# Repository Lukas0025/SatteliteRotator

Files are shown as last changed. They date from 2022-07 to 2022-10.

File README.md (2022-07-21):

# Sattelite (antenna) Rotator (OpenSource and Open-source hardware) (HamLIB, Gpredict, satNOGS) (Linear motor EL)

Simple arduino antenna rotator with two axis (AZ and EL). For AZ is used step motor and for EL is used linear motor. 
For controll is created PCB with Arduino nano, step motor driver and four relays. Controller uses easycomm and rotator can work with HAM Lib, Gpredict, SatNOGS, ...

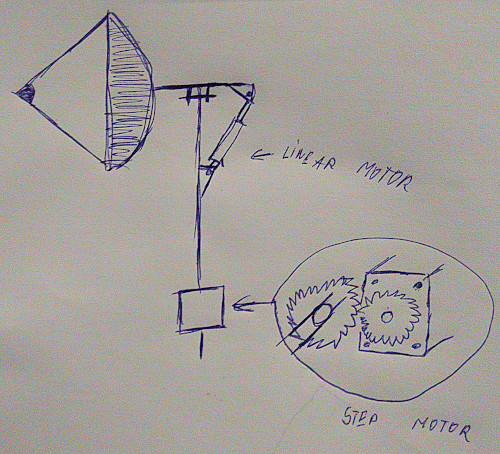
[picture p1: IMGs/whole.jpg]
Whole


## Rotator setup

### Azimuth

For azimuth rotator can by used simply one gear on rope and step motor like here https://www.thingiverse.com/thing:4246844 or can by used some old HAM rotator and replace rotary pin with step motor.

* Step motor and rope

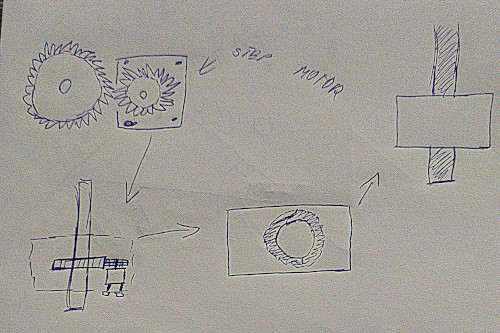
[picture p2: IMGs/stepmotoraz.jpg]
StepMotor


* Step motor and old rotator

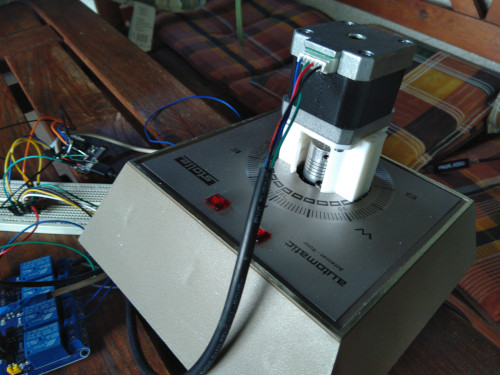
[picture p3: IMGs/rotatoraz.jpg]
OldRotator


### Elevation

For elevation is used linear motor more info is here https://www.qsl.net/sv1bsx/actuator/actuator.html

Elevation
Elevation_open

## Controller board

Board using Arduino Nano as microcontoler, A4988 for drive stepmotor, external 4 relay board for drive linear motor and same extesion ports. Board is designed in Kicad.

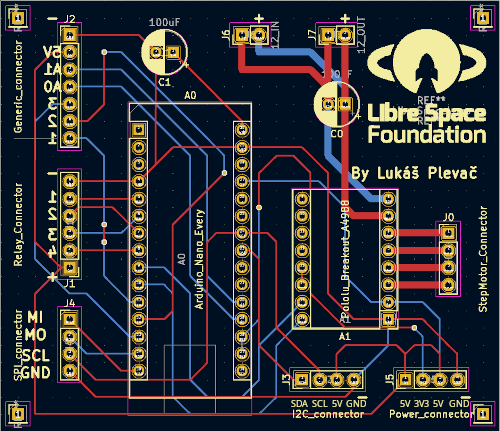
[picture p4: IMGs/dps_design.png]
Board


### Parts:

* Arduino Nano (https://www.ebay.com/itm/384943705316)
* A4988 Driver (https://www.ebay.com/itm/221921771119)
* 4 relay borad (4 channels) (https://www.ebay.com/itm/295078400027)
* 2x 100uF capacitator
* 2x 2 Pin 2.54mm Pitch PCB Screw Terminal Block (https://www.ebay.com/itm/264467271488)
* 2x 15pin 2.54mm Long Pin Female Header (https://www.ebay.com/itm/223478558792)
* 2x 8pin 2.54mm Long Pin Female Header (https://www.ebay.com/itm/223478558792)
* 1x 4pin 2.54mm Long Pin Male Header
* prited PCB 

### Extension ports

* Generic ports - 3 digitals and 2 analog ports
* SPI port
* I2C port
* power port - 5V, 3V3 and GND
* 2 relays

### Ports mapping

|  Boards | Arduino Nano |
|---|---|
| Relay 1 | D2 |
| Relay 2 | D4 |
| Relay 3 | D3 |
| Relay 4 | D5 |
| Step Motor Step  | D6 |
| Step Motor Dir | D7 |
| Generic 1 | D8 |
| Generic 2 | D9 |
| Generic 3 | D10 |
| A0 | A0 |
| A1 | A1 |
| MI | MISO |
| MO | MOSI |
| SCK | SCK |
| SDA (I2C) | SDA/A4 |
| SCL (I2C) | SCL/A5 |

## Connect with PC (HamLib, Gpredict, ...)

After code uploaded to arduino you need run rotctld for parse easycomm comunication.

```sh
sudo rotctld -m 202 -r /dev/ttyACM0 -s 9600 -T 127.0.0.1 -t 4533 -C timeout=5000 -C retry=0 -vvvvvvvv > pause
```

Connect to Gpredict using add rotator to Gpredict in Edit > Settings > Interface > Rotators > add new

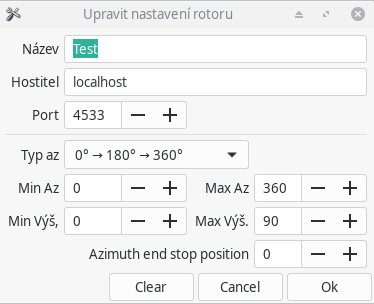
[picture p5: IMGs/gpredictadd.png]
Add New


then you can use rotator in Antenna controller

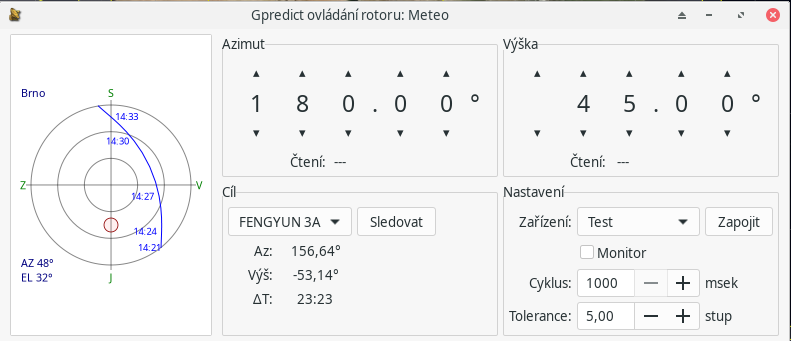
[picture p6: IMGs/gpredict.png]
Gpredict


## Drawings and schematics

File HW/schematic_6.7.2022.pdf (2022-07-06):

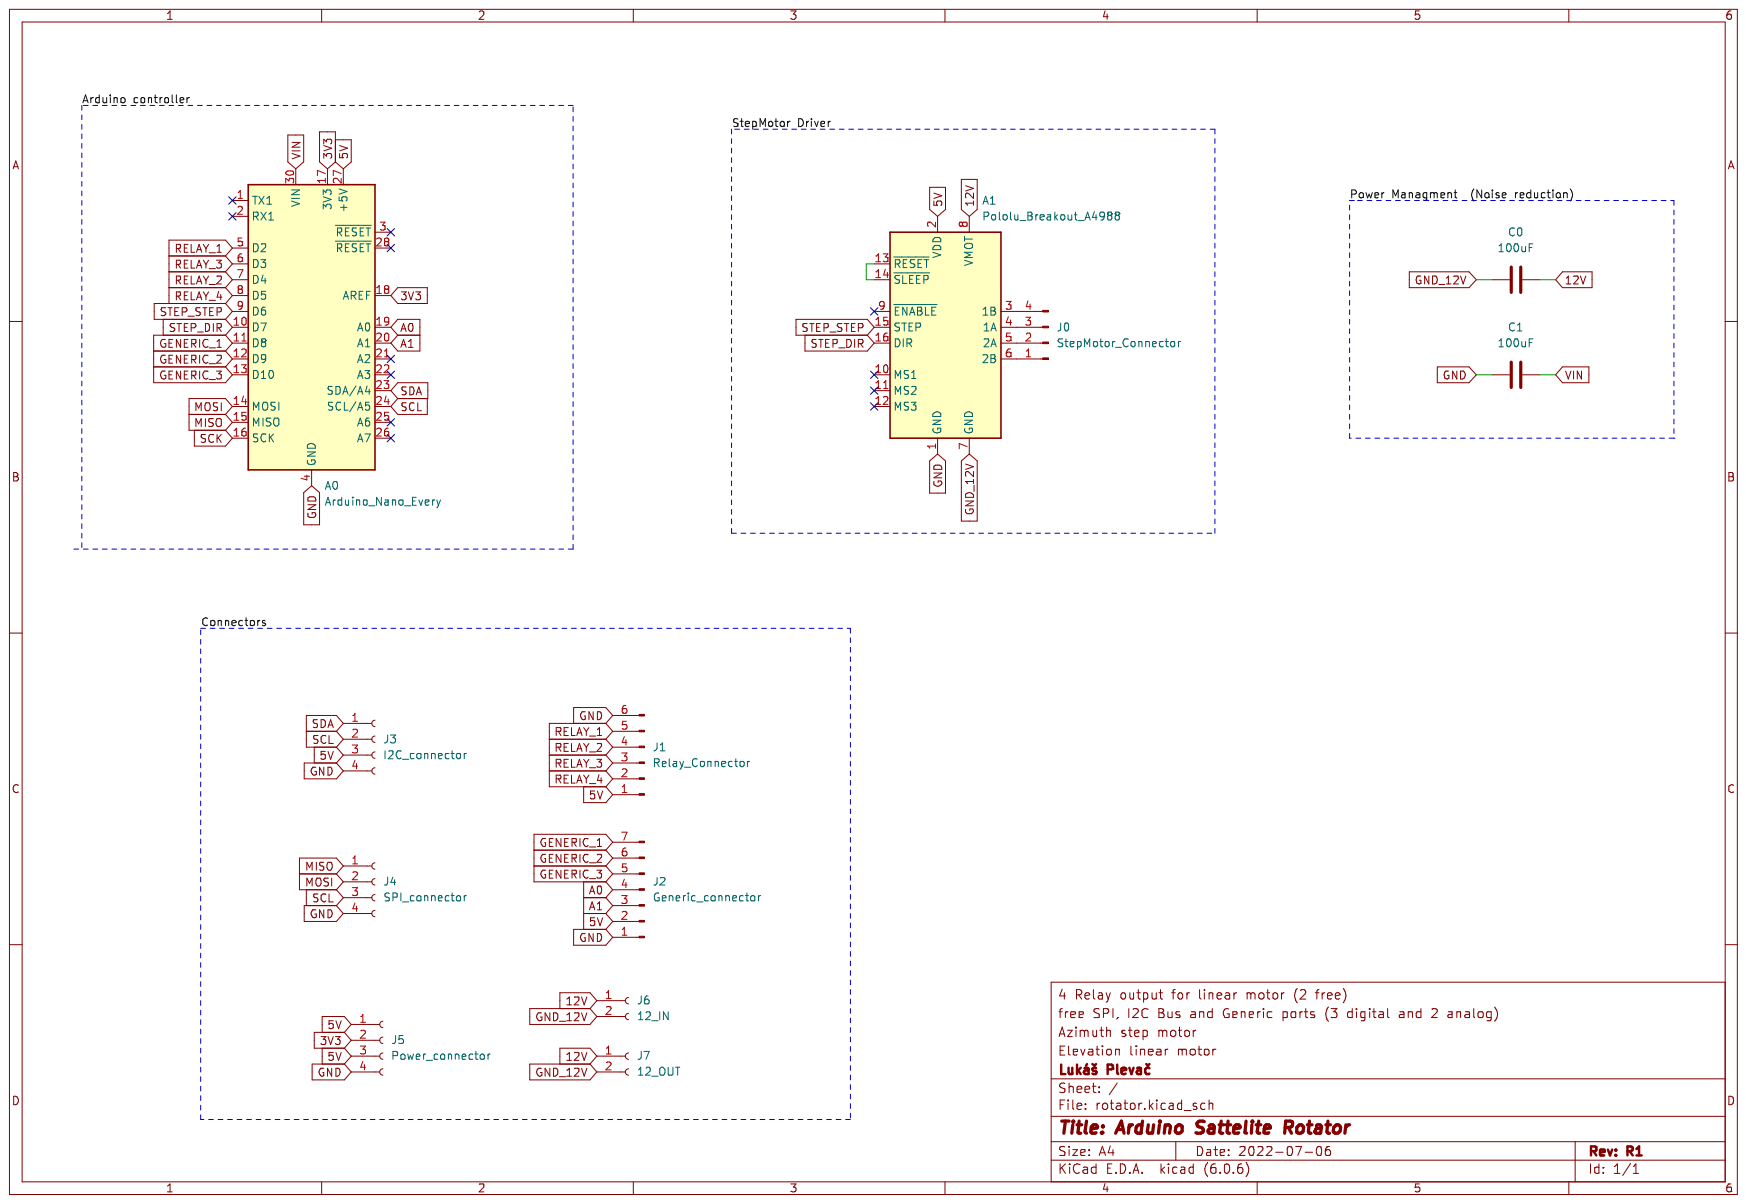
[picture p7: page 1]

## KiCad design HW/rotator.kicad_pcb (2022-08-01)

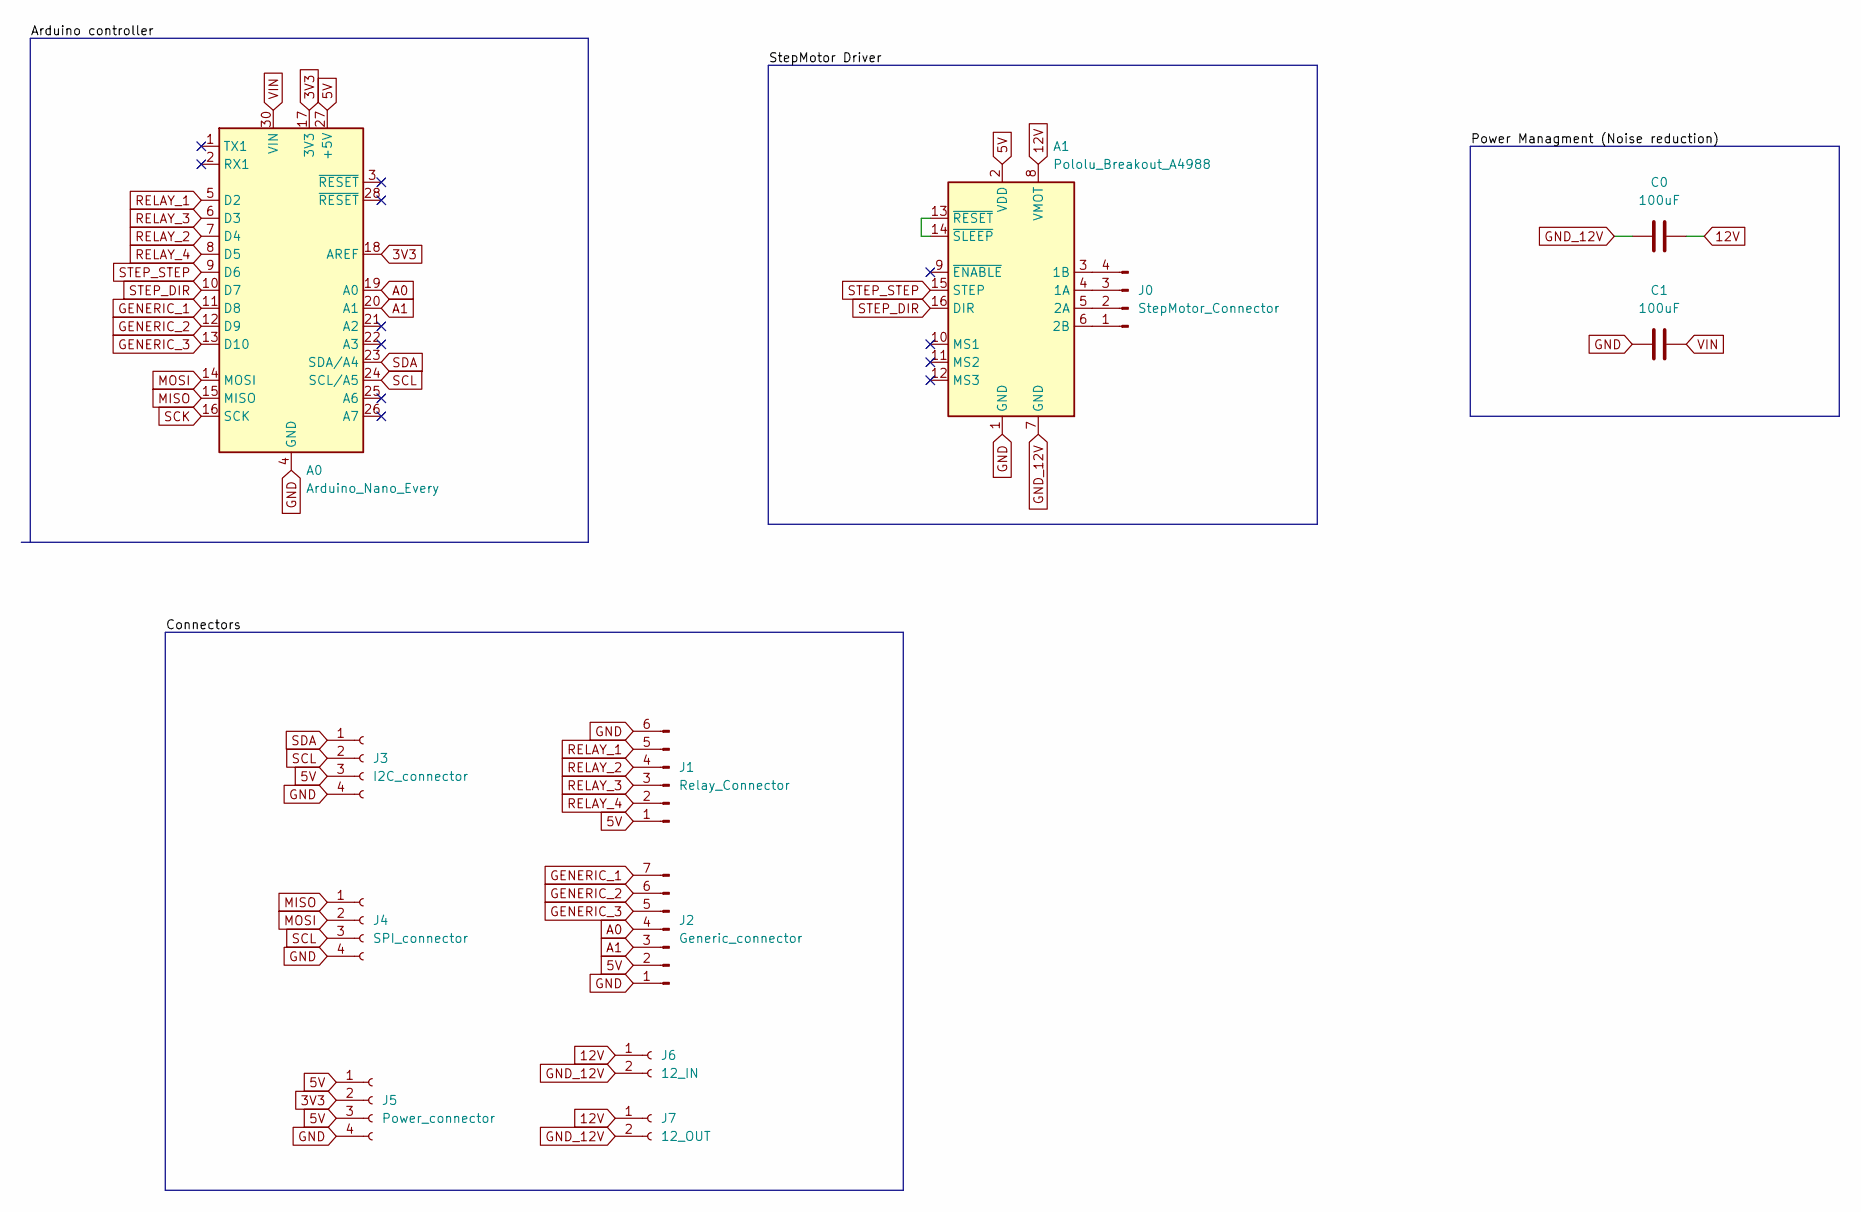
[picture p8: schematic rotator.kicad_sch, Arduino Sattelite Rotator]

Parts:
A0: Arduino_Nano_Every; Arduino_Nano
A1: Pololu_Breakout_A4988; Pololu_Breakout-16_15.2x20.3mm
C0, C1: 100uF; CP_Radial_D6.3mm_P2.50mm
J0: StepMotor_Connector; PinHeader_1x04_P2.54mm_Vertical
J1: Relay_Connector; PinHeader_1x06_P2.54mm_Vertical
J2: Generic_connector; PinHeader_1x07_P2.54mm_Vertical
J3: I2C_connector; PinHeader_1x04_P2.54mm_Vertical
J4: SPI_connector; PinHeader_1x04_P2.54mm_Vertical
J5: Power_connector; PinHeader_1x04_P2.54mm_Vertical
J6: 12_IN; PinHeader_1x02_P2.54mm_Vertical
J7: 12_OUT; PinHeader_1x02_P2.54mm_Vertical

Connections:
3V3: A0.17 (3V3), A0.18 (AREF), J5.2
5V: A0.27 (+5V), A1.2 (VDD), J1.1, J2.2, J3.3, J5.1, J5.3
12V: A1.8 (VMOT), C0.1, J6.1, J7.1
A0: A0.19 (A0), J2.4
A1: A0.20 (A1), J2.3
GENERIC_1: A0.11 (D8), J2.7
GENERIC_2: A0.12 (D9), J2.6
GENERIC_3: A0.13 (D10), J2.5
GND: A0.4 (GND), A0.29 (GND), A1.1 (GND), C1.2, J1.6, J2.1, J3.4, J4.4, J5.4
GND_12V: A1.7 (GND), C0.2, J6.2, J7.2
MISO: A0.15 (MISO), J4.1
MOSI: A0.14 (MOSI), J4.2
unnamed: A1.3 (1B), J0.4
unnamed: A1.4 (1A), J0.3
unnamed: A1.5 (2A), J0.2
unnamed: A1.6 (2B), J0.1
unnamed: A1.13 (~RESET), A1.14 (~SLEEP)
RELAY_1: A0.5 (D2), J1.5
RELAY_2: A0.7 (D4), J1.4
RELAY_3: A0.6 (D3), J1.3
RELAY_4: A0.8 (D5), J1.2
SCK: A0.16 (SCK)
SCL: A0.24 (SCL/A5), J3.2, J4.3
SDA: A0.23 (SDA/A4), J3.1
STEP_DIR: A0.10 (D7), A1.16 (DIR)
STEP_STEP: A0.9 (D6), A1.15 (STEP)
VIN: A0.30 (VIN), C1.1

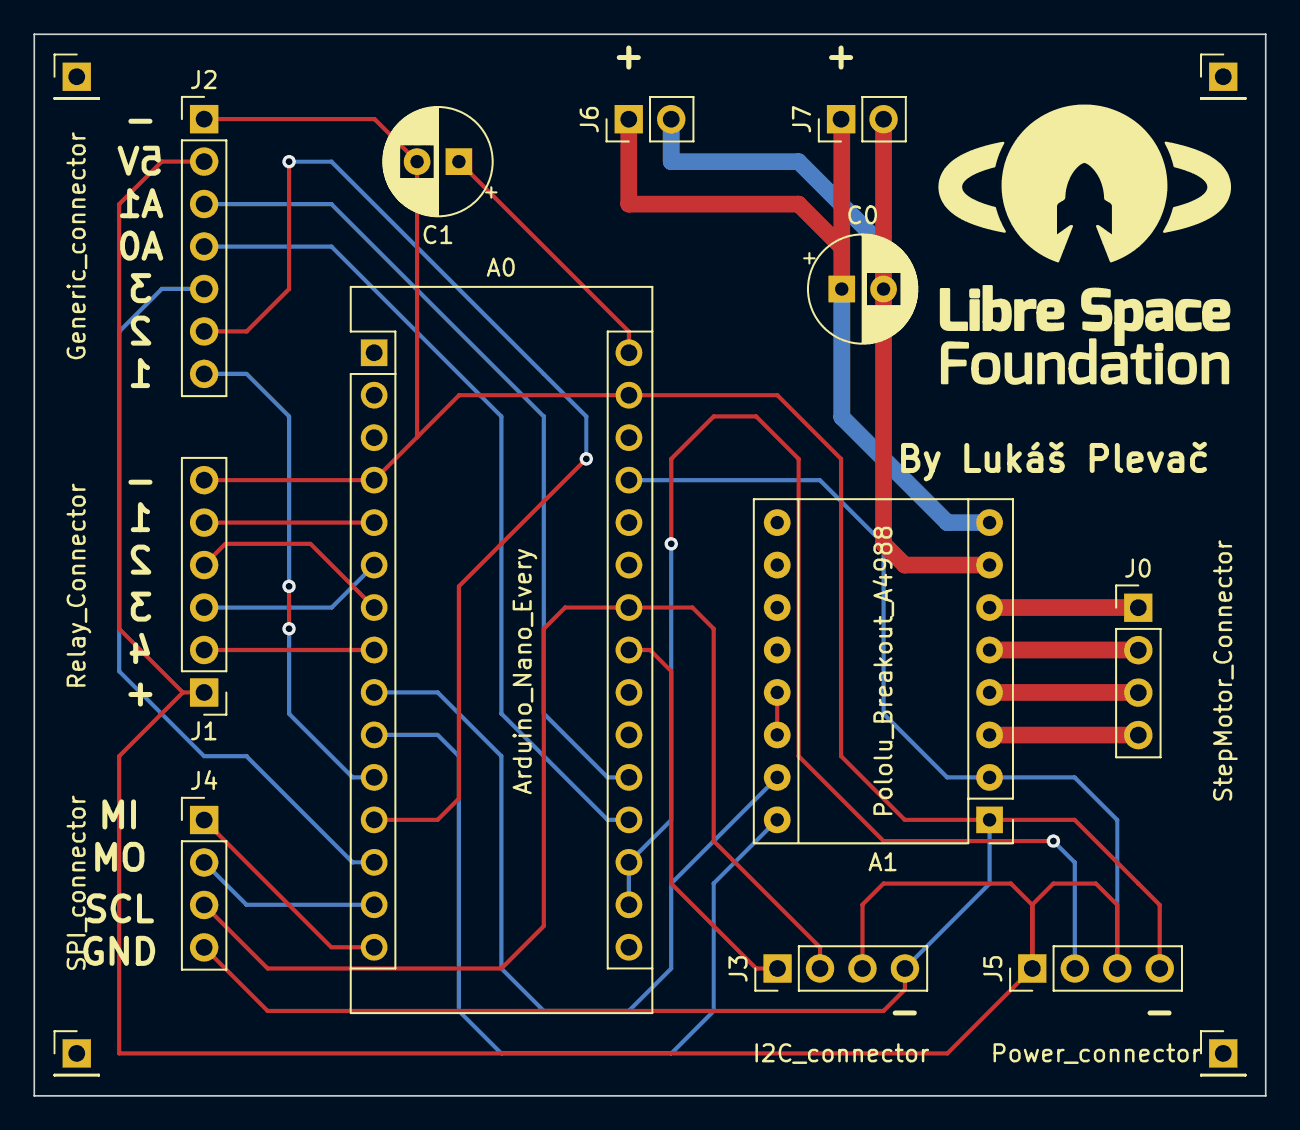
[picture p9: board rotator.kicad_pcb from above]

Board: 2 copper layers, 73.7 x 63.5 mm, 12 parts (0 on the bottom side), 26 nets.

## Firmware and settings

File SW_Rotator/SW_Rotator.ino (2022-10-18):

#include "easycomm.h"
#include "librespace_rotator_pins.h"
#include "linear_motor.h"
#include "step_motor.h"

#define USE_AZ_NOTIFY_RELAY
#define RELAY_ON LOW
#define RELAY_OFF HIGH
#define NOTIF_RELAY RELAY_2

#define AZ_DIR_PIN MOTOR_DIR
#define AZ_STEP_PIN MOTOR_STEP
#define AZ_STEP_SPEED 40
#define AZ_STEPS_PER_DEG 137
#define AZ_MAX_DEG 360
#define AZ_RESTART_DEG_COUNT 360 * 2

#define AZ_OFFSET 180

#define EL_POS_PIN RELAY_3
#define EL_NEG_PIN RELAY_4
#define EL_STEP_COUNT_MAX 29000
#define EL_MAX_DEG 81
#define EL_TIME_PER_DEG_COUNT 358
#define EL_DEG_COUNT_PER_TIME 1
#define EL_RESTART_DEG_COUNT 90 * 4

#define EL_OFFSET 15

linear_motor *el;
step_motor *az;
easycomm *easycom;

bool last_az_step = false;

void setup() {
  pinMode(RELAY_1, OUTPUT);
  pinMode(RELAY_2, OUTPUT);
  pinMode(RELAY_3, OUTPUT);
  pinMode(RELAY_4, OUTPUT);

  digitalWrite(RELAY_1, RELAY_OFF);
  digitalWrite(RELAY_2, RELAY_OFF);
  digitalWrite(RELAY_3, RELAY_OFF);
  digitalWrite(RELAY_4, RELAY_OFF);

  el = new linear_motor(EL_POS_PIN, EL_NEG_PIN, EL_STEP_COUNT_MAX, EL_MAX_DEG,
                        EL_RESTART_DEG_COUNT);
  el->set_step(EL_DEG_COUNT_PER_TIME, EL_TIME_PER_DEG_COUNT);

  az = new step_motor(AZ_STEP_PIN, AZ_DIR_PIN, AZ_STEP_SPEED, AZ_STEPS_PER_DEG,
                      AZ_MAX_DEG, AZ_RESTART_DEG_COUNT);

  Serial.begin(9600);
  Serial.setTimeout(50);

  easycom = new easycomm(&Serial);
}

void loop() {
  easycom->parse((az->get_deg() + AZ_OFFSET) % AZ_MAX_DEG,
                 el->get_deg() - EL_OFFSET);

  el->set_target(easycom->ComElev + EL_OFFSET);
  el->step();

  az->set_target((easycom->ComAzim + AZ_OFFSET) % AZ_MAX_DEG);
  bool az_step = az->step();

#ifdef USE_AZ_NOTIFY_RELAY
  if (az_step) {
    // notify
    digitalWrite(NOTIF_RELAY, RELAY_ON);
    delay(200);
    digitalWrite(NOTIF_RELAY, RELAY_OFF);
  }

  last_az_step = az_step;
#endif
}

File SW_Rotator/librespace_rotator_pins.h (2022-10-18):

#pragma once

#include <Arduino.h>

#define RELAY_1 2
#define RELAY_2 4
#define RELAY_3 3
#define RELAY_4 5

#define GPIO_1 8
#define GPIO_2 9
#define GPIO_3 10

#define A_0 A0
#define A_1 A1

#define MI 12
#define MO 11
#define SCK 13
#define SDA A4
#define SCL A5

#define MOTOR_DIR 7
#define MOTOR_STEP 6

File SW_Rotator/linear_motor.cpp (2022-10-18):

#include "linear_motor.h"

int linear_motor::get_deg() { return this->current; }

void linear_motor::set_step(int deg, int times) {
  this->step_deg = deg;
  this->step_time = times;
}

void linear_motor::set_target(int deg) {
  this->target = (deg > this->max_deg) ? this->max_deg : deg;
}

void linear_motor::step() {
  if (abs(this->current - this->target) > DEG_TOLERANCE) {
    if (this->trevled_deg + abs(this->current - this->target) >
        this->restart_deg_count)
      this->home();

    if (this->current < this->target) {
      if (this->current >= this->max_deg)
        return;
      this->motor_up(this->step_time);
      this->current += this->step_deg;
    } else {
      if (this->current <= 0)
        return;

      this->motor_down(this->step_time);
      this->current -= this->step_deg;
    }

    this->trevled_deg += this->step_deg;
  }
}

void linear_motor::motor_down(int times) {
  digitalWrite(this->ports.n, MOT_OFF);
  digitalWrite(this->ports.p, MOT_ON);
  delay(times);
  digitalWrite(this->ports.p, MOT_OFF);
  digitalWrite(this->ports.n, MOT_OFF);
  delay(times);
}

void linear_motor::motor_up(int times) {
  digitalWrite(this->ports.p, MOT_OFF);
  digitalWrite(this->ports.n, MOT_ON);
  delay(times);
  digitalWrite(this->ports.n, MOT_OFF);
  digitalWrite(this->ports.p, MOT_OFF);
  delay(times);
}

void linear_motor::home() {
  for (int i = 0; i < full_milis; i += 1000) {
    this->motor_down(1000);
  }

  this->trevled_deg = 0;
  this->current = 0;
  this->target = 0;
}

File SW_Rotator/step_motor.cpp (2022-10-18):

#include "step_motor.h"

int step_motor::get_deg() { return (int)this->current; }

void step_motor::set_target(int deg) {
  this->target =
      (deg + this->offset > this->max_deg) ? this->max_deg : deg + this->offset;
}

bool step_motor::step() {
  if (abs(this->current - this->target) > DEG_TOLERANCE) {

    this->trevled_deg += abs(this->current - this->target);
    if (this->trevled_deg > this->restart_deg_count)
      this->home();

    float steps = abs(this->current - this->target) / this->step2deg;

    if (this->current < this->target) {
      if (this->current >= this->max_deg)
        return false;

      this->motor_down(steps);
      this->current += steps * this->step2deg;
    } else {
      if (this->current <= 0)
        return false;

      this->motor_up(steps);
      this->current -= steps * this->step2deg;
    }

    return true;
  }

  return false;
}

void step_motor::motor_down(float steps) {
  this->stepper.setCurrentPosition(0);
  this->stepper.setSpeed(-this->step_speed);
  while (stepper.currentPosition() > -steps) {
    this->stepper.runSpeed();
  }
}

void step_motor::motor_up(float steps) {
  this->stepper.setCurrentPosition(0);
  this->stepper.setSpeed(this->step_speed);
  while (stepper.currentPosition() < steps) {
    this->stepper.runSpeed();
  }
}

void step_motor::home() {
  this->motor_up(this->step_count);
  this->trevled_deg = 0;
  this->current = 0;
  this->target = 0;
}

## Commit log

2022-07-06 Added HW and basic documenation
    [rotator.kicad_pcb, rotator.kicad_sch]
2022-07-06 Added gerber
2022-07-06 Added pdf schematic
2022-07-06 added info about I2C
2022-07-07 Added connectors
2022-07-21 Fixed C1 polarization in DPS
    [rotator.kicad_pcb, rotator.kicad_sch]
2022-08-01 Fixed capacitator C0 polarization
    [rotator.kicad_pcb, rotator.kicad_sch]
